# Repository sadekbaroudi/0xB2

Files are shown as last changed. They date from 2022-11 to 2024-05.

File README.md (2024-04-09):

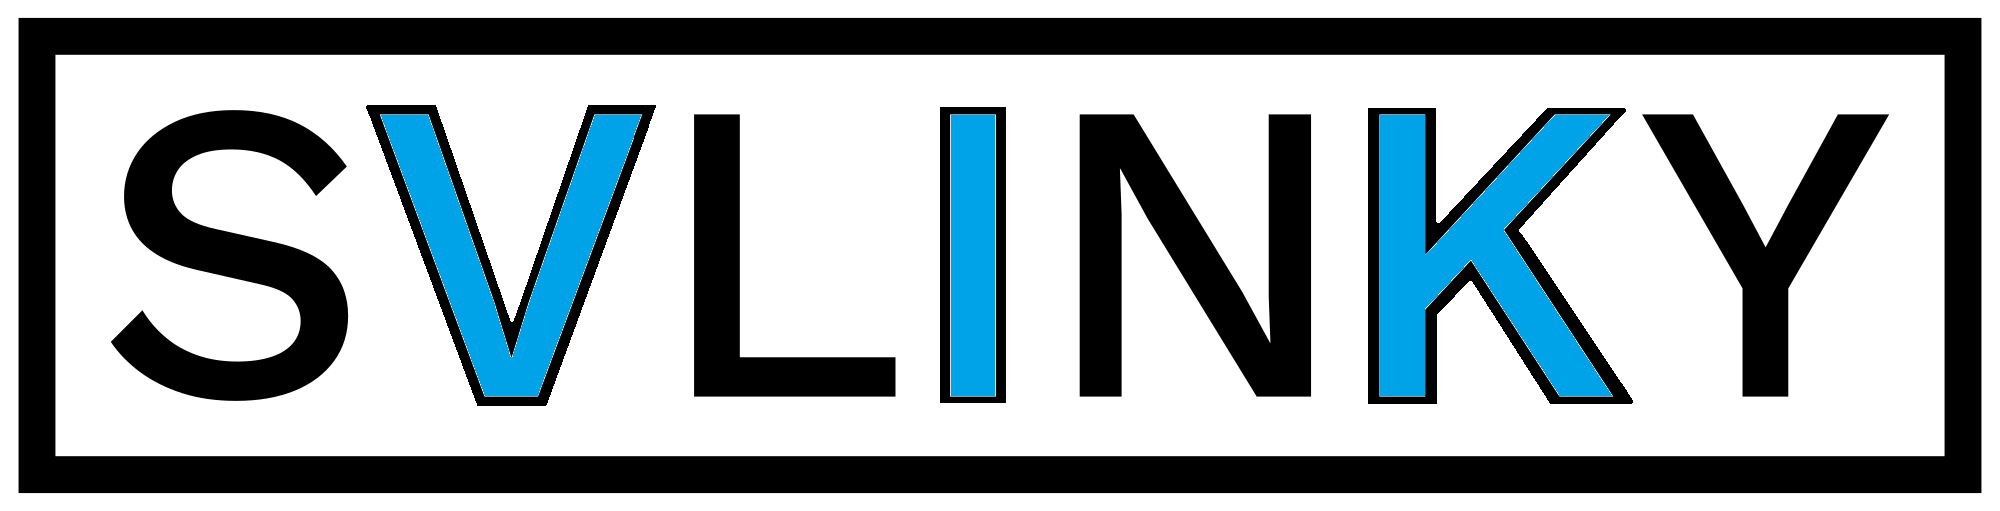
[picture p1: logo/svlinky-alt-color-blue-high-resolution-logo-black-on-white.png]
svlinky-logo


# SVLINKY
##  Summary

Pro Micro footprint with USB-C, RP2040, and a [VIK](https://github.com/sadekbaroudi/vik) connector

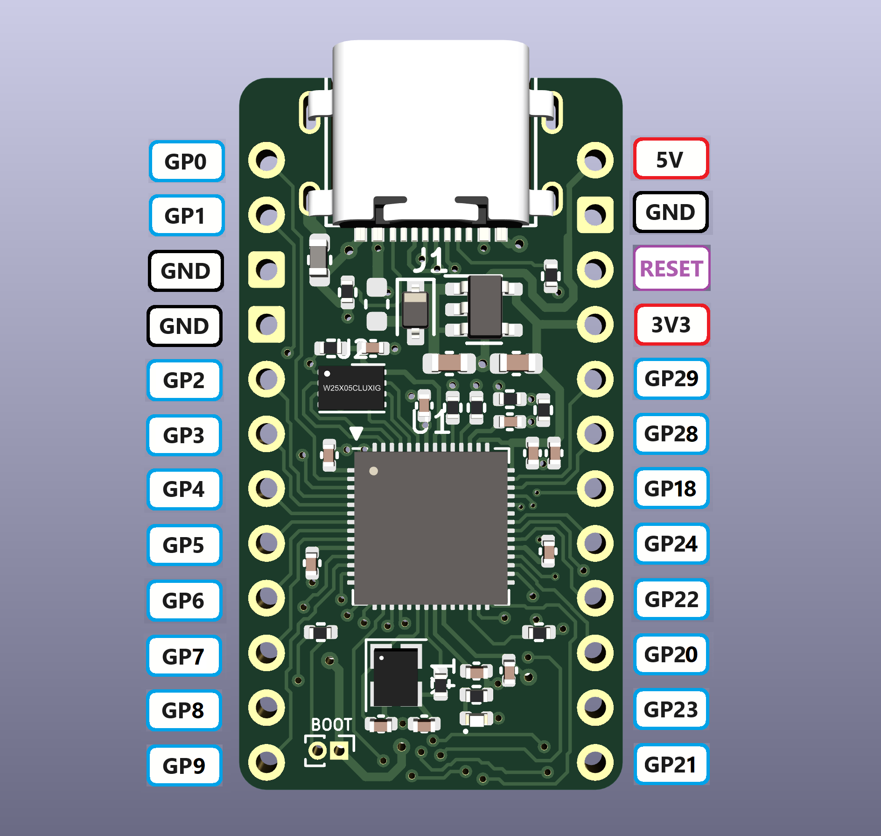
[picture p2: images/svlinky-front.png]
svlinky front

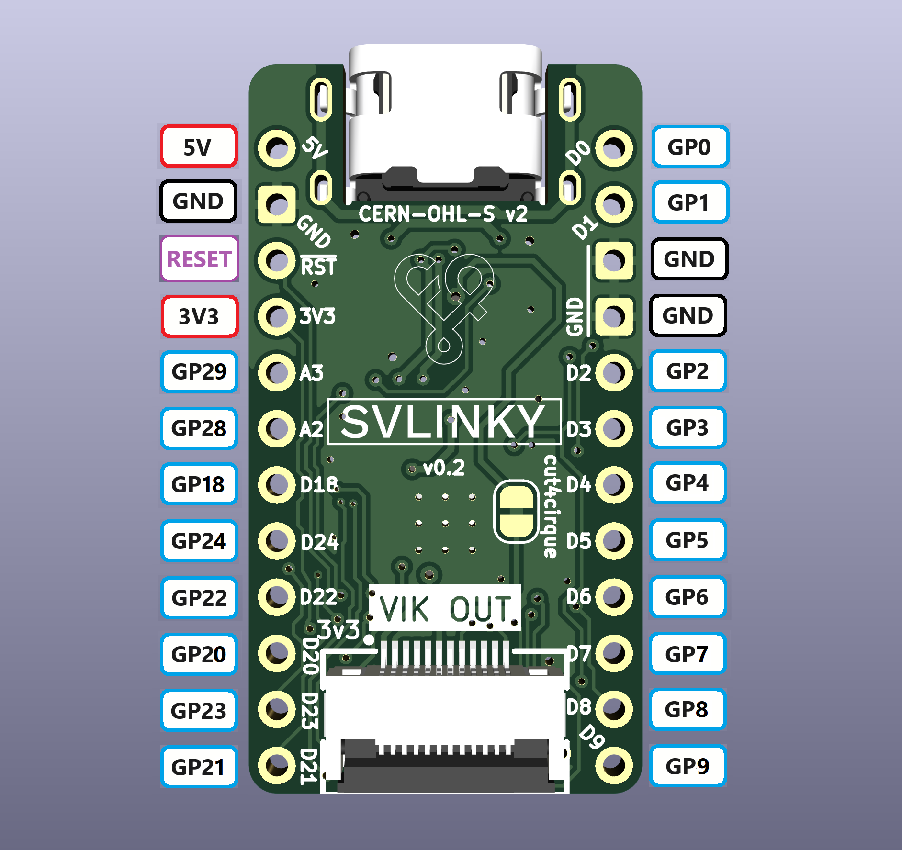
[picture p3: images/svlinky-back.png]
svlinky back


## Features

 * Pro-micro / Sparkfun RP2040 compatible footprint, with VIK connector on the bottom
 * Raspberry Pi RP2040 MCU
 * Up to 16MB flash memory _(depending on component selection and availability)_
 * USB VBUS detect
 * Low profile USB-C mid-mount connector
 * Designed to be manufactured and assembled by all common PCBA services (including JLCPCB)

## Pinout

USB VBUS detection on GPIO19.

TODO: put together detailed pinout with reference images

### v0.2

The pinout changed in order to accommodate [VIK](https://github.com/sadekbaroudi/vik) analog pin specification. See the following [pull request](https://github.com/sadekbaroudi/svlinky/pull/2) to review the changes.

### v0.1

The pinout is compatible with the widely available [SparkFun RP2040](https://www.sparkfun.com/products/18288), but has almost all the additional GPIO from the RP2040 broken out to the VIK connector on the bottom of the controller.

## Programming

In order to put the board in bootloader mode, quickly short the RESET and ground pins (marked **R** and **GND**) while shorting the two through holes on the bottom half of the controller on the top side.

Note: If mounting the controller with components face down, you will lose access to the BOOT through holes. Before mounting the controller, you can solder short wires to these through holes so you can access them. This is only necessary if you can't trigger the bootloader by shorting the RESET and GND pins. The likelihood is that you'll never need to do the BOOT method if using this for a mechanical keyboard running QMK, for example.

## Firmware

### v0.2 firmware

There is no reference firmware for this yet, but I will be including both QMK and ZMK firmware.

QMK will be here: https://github.com/sadekbaroudi/qmk_firmware/tree/develop_fingerpunch/keyboards/fingerpunch/svlinky  

ZMK will be here: https://github.com/sadekbaroudi/zmk_fingerpunch_controllers  

### v0.1 firmware

As of this writing (2023-09-14), I have written and tested firmware for the SVLINKY using QMK and a collection of VIK modules.

You can use this as a reference:
https://github.com/sadekbaroudi/qmk_firmware/tree/develop_fingerpunch/keyboards/fingerpunch/svlinky

This QMK firmware has everything mapped out such that you can copy it as a starting point, and modify/add/remove pin mappings based on the board that you are connecting the SVLINKY to.

At some point, I'd also like to add a SVLINKY converter using the [QMK converters](https://github.com/qmk/qmk_firmware/blob/master/docs/feature_converters.md) framework.

## Manufacturing

To manufacture the SVLINKY, you can use the files in the [pcb/production](./pcb/production/) directory.

*Note: The following instructions are based on JLCPCB's order flow, but is subject to change*

Instructions for [JLCPCB](https://jlcpcb.com)
* gerbers - upload these from the main PCB screen
  * Be sure to PCB Assembly
  * For PCBA type, select Standard
  * For Assembly Side, select Both Sides
  * Click Confirm
* Click next until you get to the bill of materials
* Upload both the bom.csv and the positions.csv (found in the gerber.zip file)
* Double check that all the components are placed appropriately
* Order!

## Credits

Special thanks to:

 * **plut0nium for creating the splinky. I used that as a base for this controller.**
 * pyntiehet for coming up with the name
 * jasonhazel, AlaaSaadAbdo, deltawhy, yingeling, bom, ridingintraffic, and the rest of the fingerpunch discord server for always being there to give great input and suggestions!

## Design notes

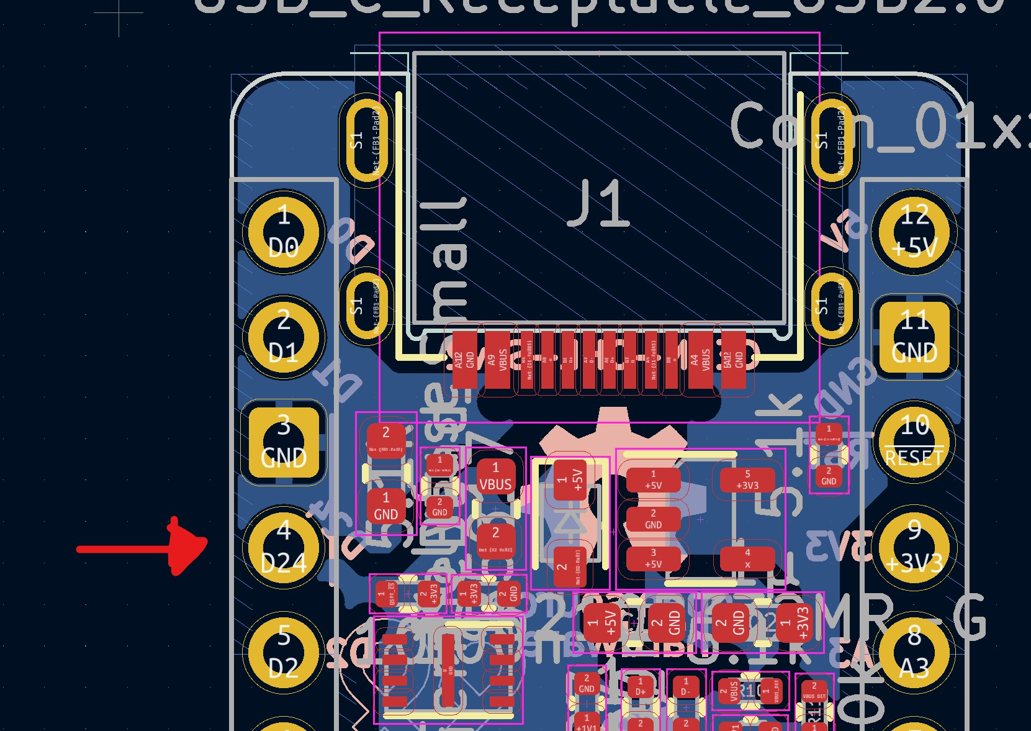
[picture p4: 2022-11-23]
pcb/doc/splinky-ground-mod.jpg

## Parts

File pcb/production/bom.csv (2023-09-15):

Designator | Footprint | Quantity | Value | LCSC Part #
C1, C2 | 0603 | 2 | 1µ | C19666
C10, C11, C12, C13, C14, C7, C8, C9 | 0402 | 8 | 100n | C1525
C3, C4 | 0402 | 2 | 15p | C1548
C5, C6 | 0402 | 2 | 1µ | C52923
D1 | 0402 | 1 | LED | C130719
D2 | D_SOD-323 | 1 | B5817 | C123899
F1 | 0603 | 1 | Polyfuse | C69679
FB1 | 0603 | 1 | FerriteBead_Small | C98288
J1 | USB_C_Receptacle_HRO_TYPE-C-31-M-13B | 1 | USB_C_Receptacle_USB2.0 | C2848619
J6 | vik-keyboard-connector-horizontal | 1 | ~ | C479750
JP1 | SolderJumper-2_P1.3mm_Bridged_RoundedPad1.0x1.5mm | 1 | Jumper_2_Bridged
R1, R3, R8 | 0402 | 3 | 1k | C11702
R10, R4, R5 | 0402 | 3 | 5.1k | C25905
R11, R2, R9 | 0402 | 3 | 10k | C25744
R6, R7 | 0402 | 2 | 27 | C25100
U1 | QFN-56-1EP_7x7mm_P0.4mm_EP3.2x3.2mm | 1 | RP2040 | C2040
U2 | USON-8-1EP_3x2mm_P0.5mm_EP0.25x1.65mm | 1 | GD25Q80CEIGR | C395484
U3 | SOT-23-5 | 1 | XC6210B332MR-G | C82942
Y1 | Crystal_SMD_2520-4Pin_2.5x2.0mm | 1 | Crystal_GND24 | C2149204

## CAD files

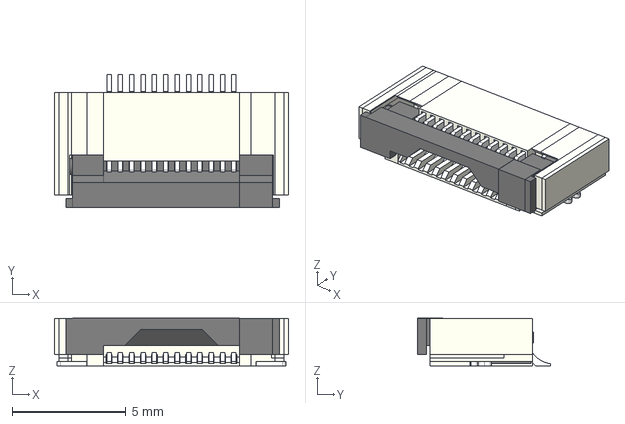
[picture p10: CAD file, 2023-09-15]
pcb/vik/vik.step/vik-connector-horizontal.stp
10.3 x 5.85 x 2.11 mm

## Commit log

2022-11-23 converted bottom gnd to use D24 on the RP2040 for one extra gpio
    [0xB2-B_Cu.gbl, 0xB2-B_Mask.gbs, 0xB2-B_Silkscreen.gbo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]
2022-11-23 added fingerpunch logo, and documentation
    [0xB2-B_Cu.gbl, 0xB2-B_Mask.gbs, 0xB2-B_Silkscreen.gbo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]
2023-08-23 converted to pro micro footprint, and added vik connector, removing bottom pins is fine, since 4 of the 5 are used for SPI via VIK anyway
    [0xB2.kicad_pcb, 0xB2.kicad_sch]
2023-08-23 added jumper for cirque support via FPC, and silk screen updates
    [0xB2.kicad_pcb, 0xB2.kicad_sch]
2023-08-23 switched the VIK analog pins to digital only, breaking VIK specs, but had to be done to avoid repurposing the analog pins that are exposed by the controller
    [0xB2.kicad_pcb, 0xB2.kicad_sch]
2023-09-05 changed silk for cirque jumper, and changed the jumper from two wires to one wire
    [0xB2.kicad_pcb, 0xB2.kicad_sch]
2023-09-15 added 3d models for render, updated readme with render, updated silkscreen
    [0xB2.kicad_pcb, 0xB2.kicad_sch, vik-connector-horizontal.stp]
2023-09-15 gitignore was excluding csvs, allowing for bom and pos files
    [bom.csv, designators.csv, positions.csv]
2024-04-08 v0.2 - changed pinout to adhere completely to VIK, now has analog compatible pins in vik's GPIO_AD1 and GPIO_AD2
    [0xB2.kicad_pcb, 0xB2.kicad_sch, bom.csv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]
